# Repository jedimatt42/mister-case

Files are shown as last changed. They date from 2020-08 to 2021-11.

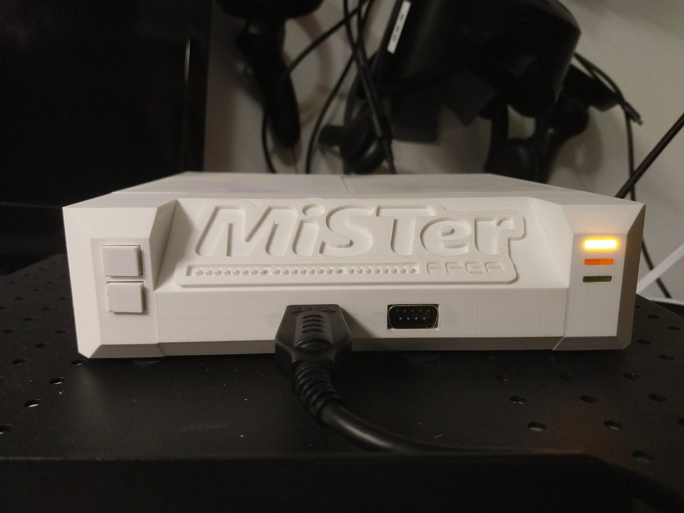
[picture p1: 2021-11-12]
images/front.jpg

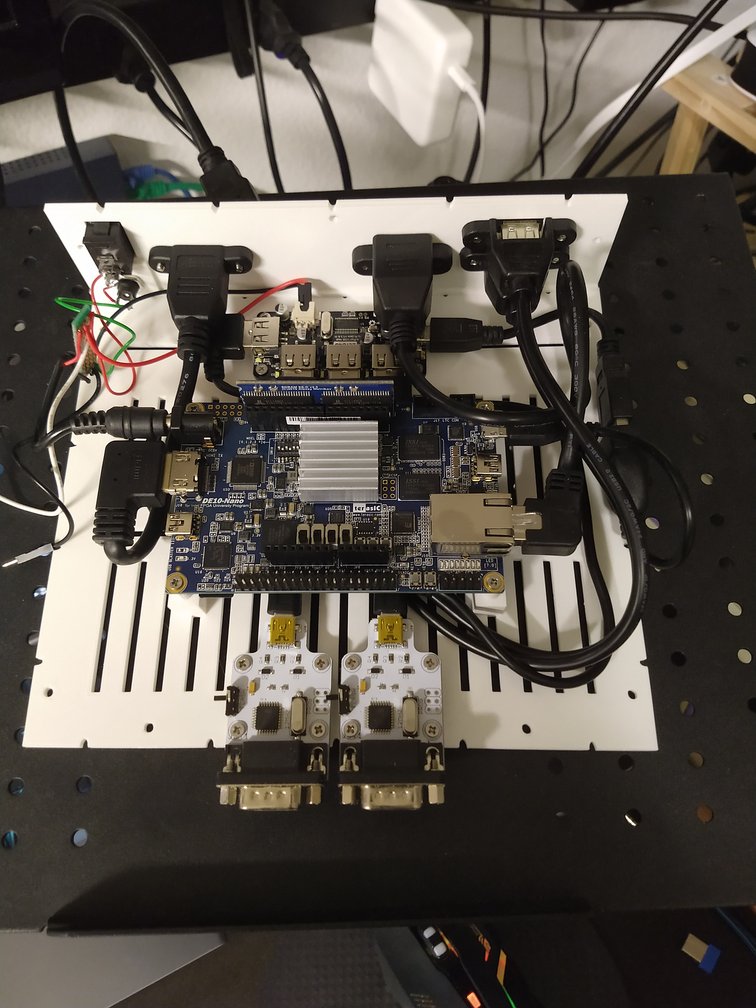
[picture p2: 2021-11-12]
images/guts.jpg

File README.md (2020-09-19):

# Custom MiSTer FPGA case

Designed to hold DE-10 Nano & slim 128MB SDRAM XS-D v2.5 boards

* Zero4U USB 2.0 powered USB hub
* With panel mount cables to bring ports to the back.
  * 2x powered USB
  * Ethernet
  * HDMI
  * 5v Power In
  * Power Switch
* 5v 30mm fan

Stylish front panel design with standard MiSTer switches and LEDs.

Note wiring of switches and LEDs from ioboard schematic:

https://github.com/MiSTer-devel/Hardware_MiSTer/blob/master/releases/iobrd_6.1.pdf

## LED

The GPIO pins appear to be active LOW, so the GND or cathode connects to the GPIO.
The anode is connected to 3.3v pin GPIO1[29] through individual 220-560 ohm resisters.

* `user` : GPIO1 pin 1  - RED
* `disk` : GPIO1 pin 3  - GREEN
* `power` : GPIO1 pin 5 - YELLOW

Connect a common lead from pin 29 to 3 resisters, each of which goes to an led, and then the negative terminal on the LED goes to the specific GPIO pin.

## Switches

switches are momentary, connecting the DE10 nano GPIO pin to GND (GPIO1[12]) when pressed.

* `reset` : GPIO1 pin 17
* `OSD`   : GPIO1 pin 13
* `user`  : GPIO1 pin 15

The left hand panel has room for 2 push button momentary switches, designed for the classic red button type: 

https://smile.amazon.com/DIYhz-Momentary-Pushbutton-Switches-Normally/dp/B08B1PWJ21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

For myself, I wire the top switch to OSD, and the bottom to USER which generally acts as in-core reset. For full MiSTer reset, the power switch on the back seems sufficient, or use the in menu option.

## LOGO for Mister

This projects uses an SVG MiSTer logo found on a forum... 

https://www.dropbox.com/s/gym92g5i8eauhdw/MISTER%20FPGA%20Logo.svg

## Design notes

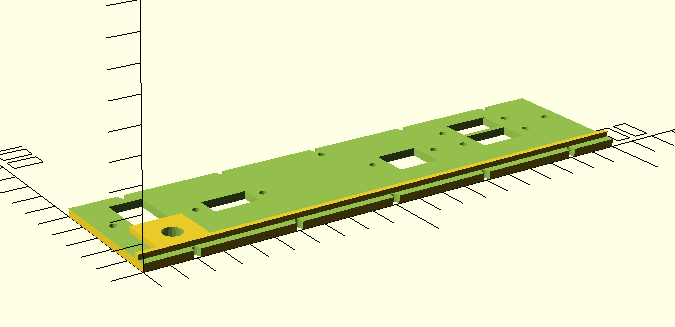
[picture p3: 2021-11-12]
images/back.png

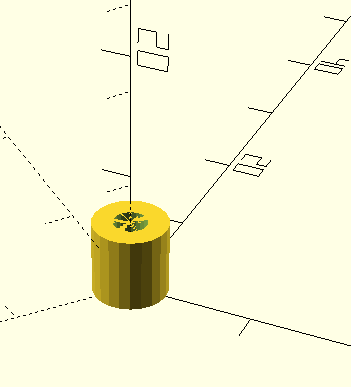
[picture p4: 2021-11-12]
images/spacer.png

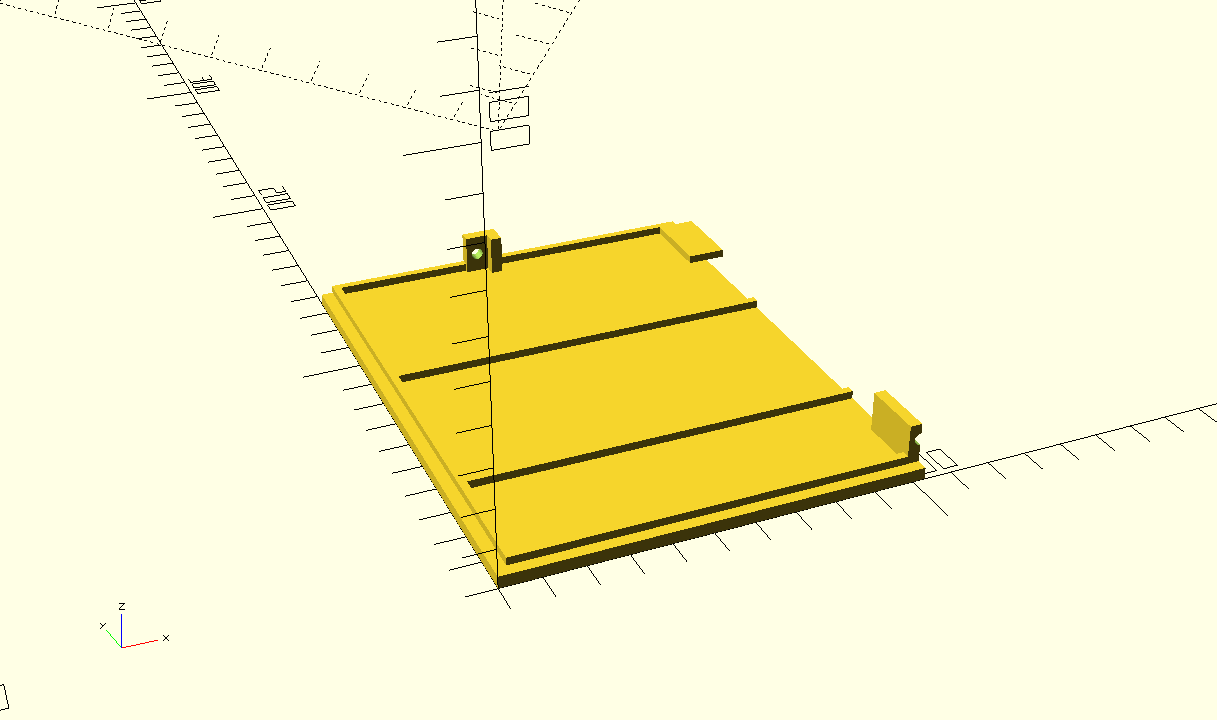
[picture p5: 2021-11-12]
images/top-left.png

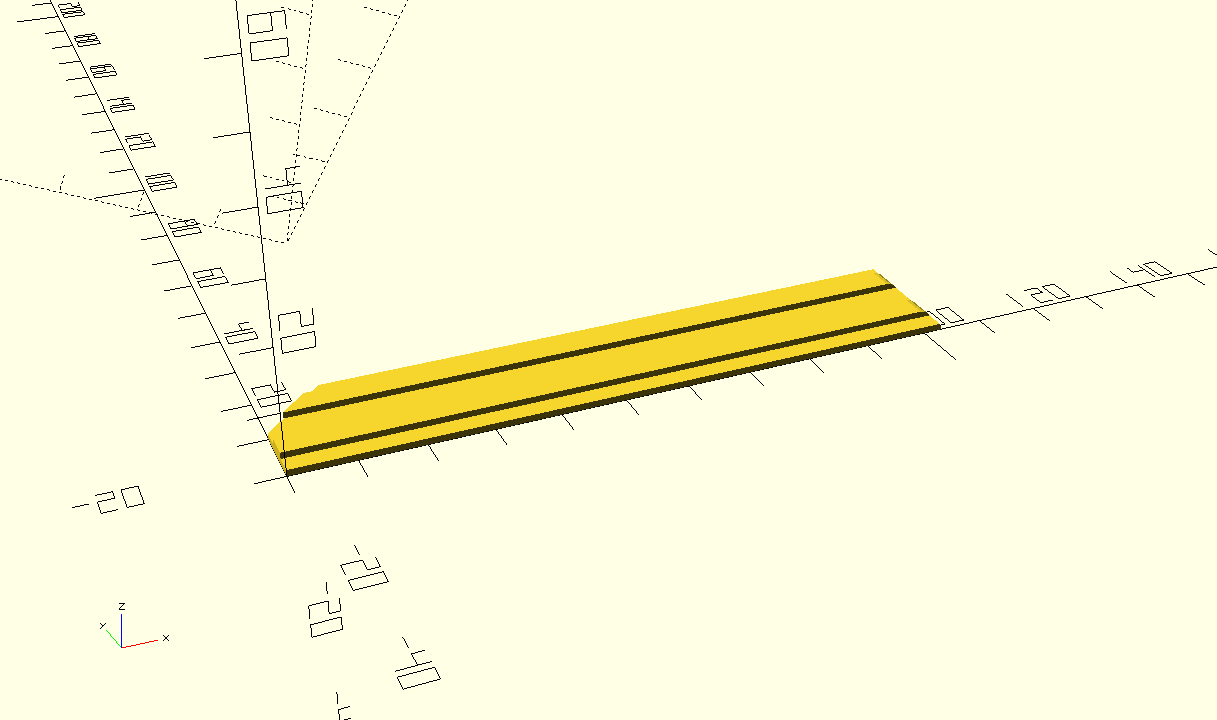
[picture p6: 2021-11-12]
images/right-seam.png

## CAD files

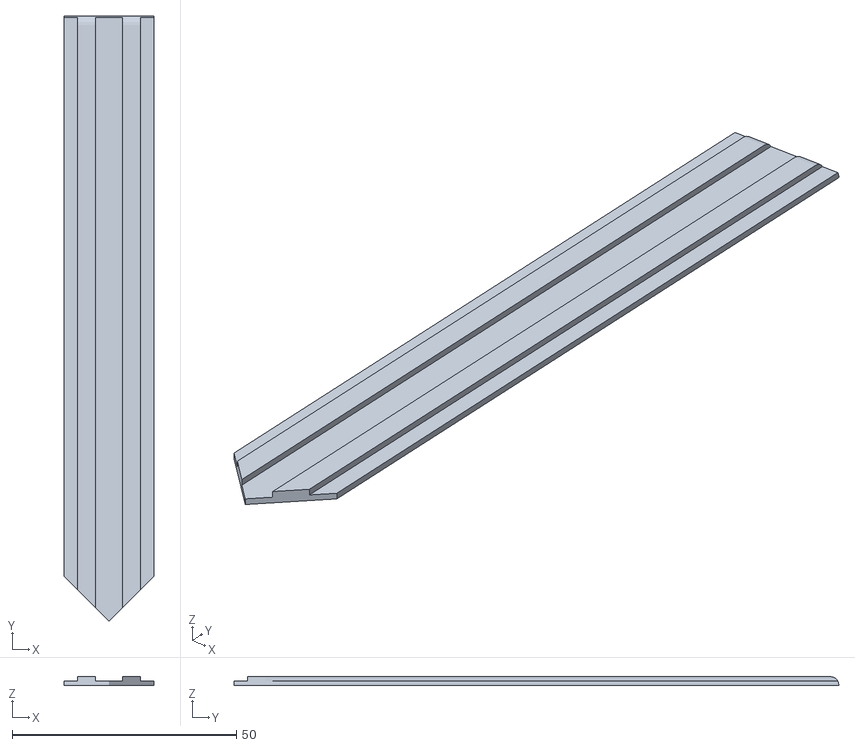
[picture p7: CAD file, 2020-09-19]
mister-console-seam-middle.stl
20.0 x 135.0 x 2.00

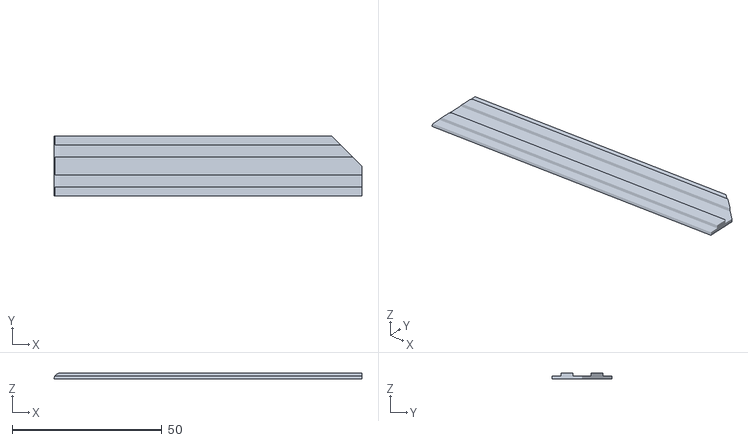
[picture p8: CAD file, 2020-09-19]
mister-console-seam-left.stl
103.0 x 20.0 x 2.00

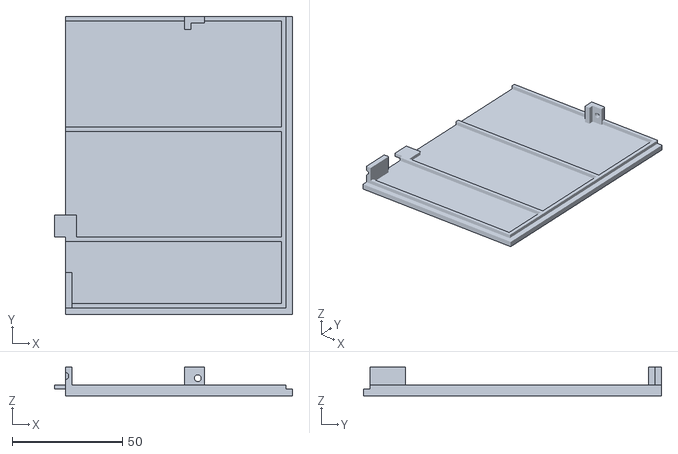
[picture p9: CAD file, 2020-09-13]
mister-console-cover-right.stl
108.0 x 135.0 x 13.0

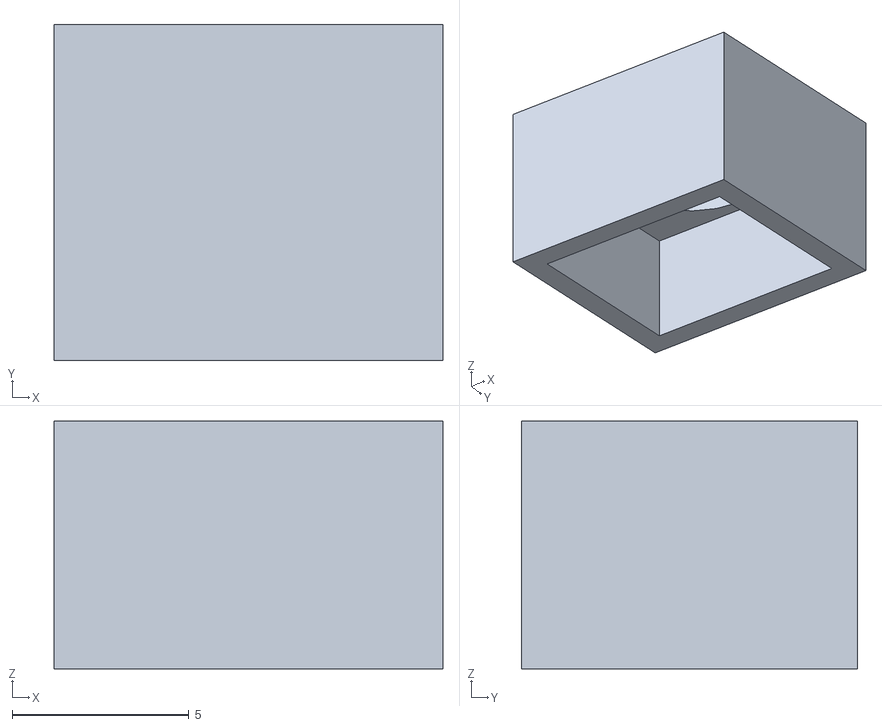
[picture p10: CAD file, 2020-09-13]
button.stl
11.0 x 9.50 x 7.00

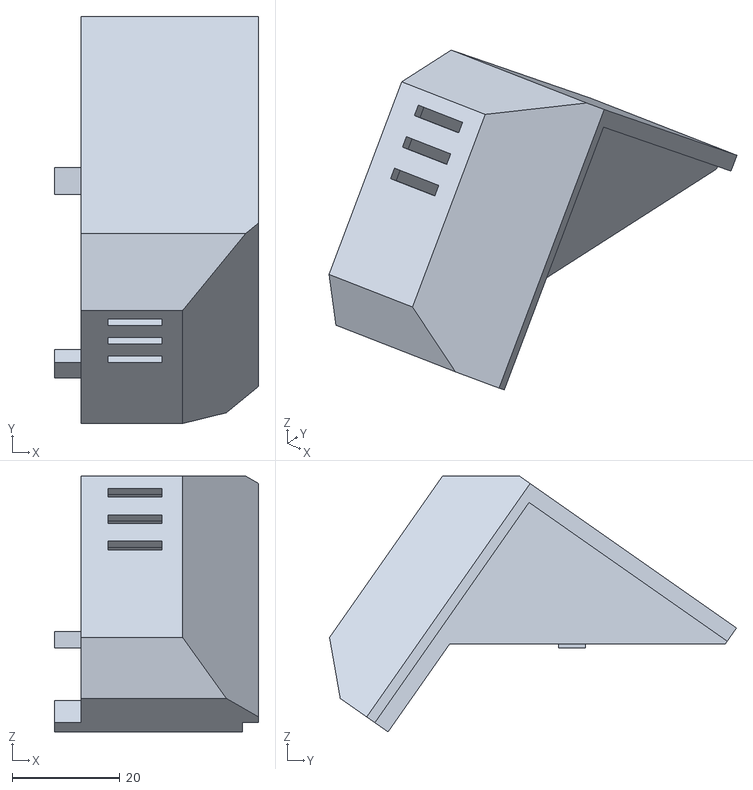
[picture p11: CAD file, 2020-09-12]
mister-console-front-right.stl
38.0 x 75.7 x 47.6

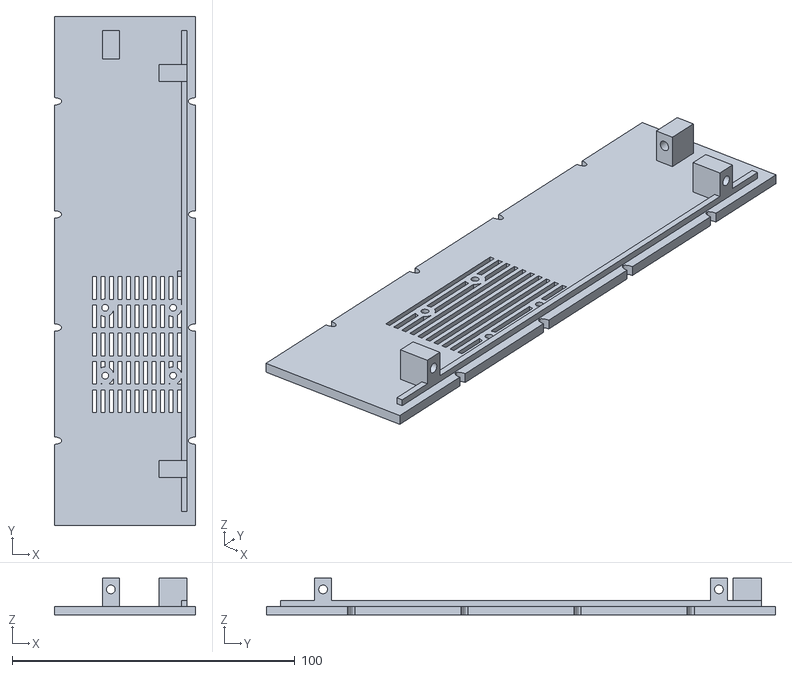
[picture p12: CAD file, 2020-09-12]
mister-console-left.stl
50.0 x 180.0 x 13.0

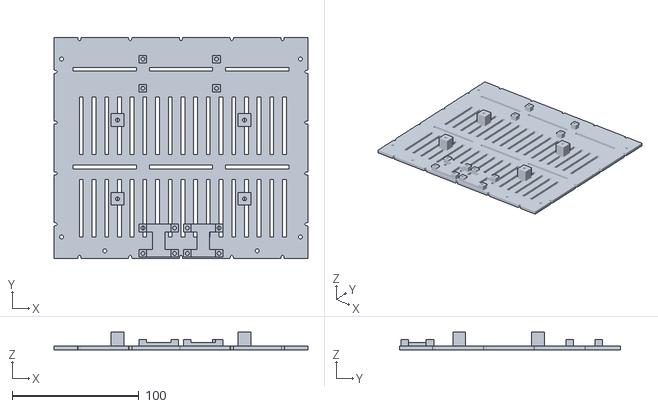
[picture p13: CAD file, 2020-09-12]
mister-console-bottom.stl
200.0 x 174.0 x 14.0

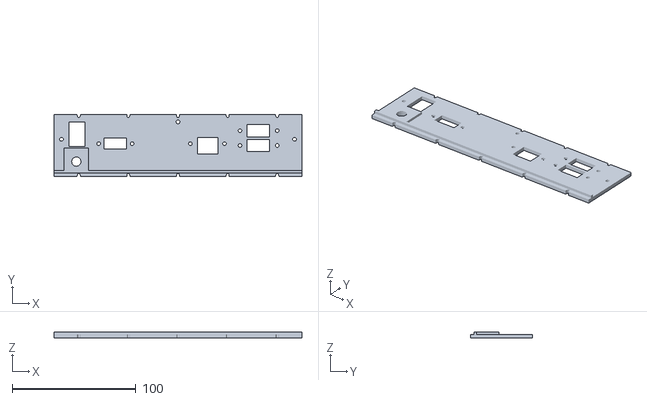
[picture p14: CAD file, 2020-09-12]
mister-console-back.stl
200.0 x 50.0 x 5.00

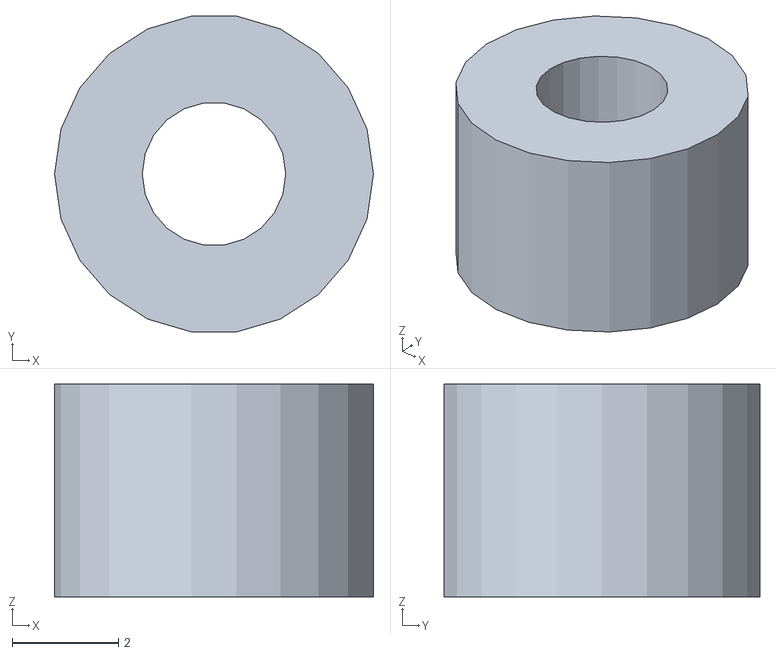
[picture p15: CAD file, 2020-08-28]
spacer.stl
6.00 x 5.94 x 4.00

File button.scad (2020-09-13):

module button_cap() {
    x=11;
    z=9.5;
    
    difference() {
        cube([x,7,z]);
        
        translate([1,2.5,1])
        cube([x-2,5.5,z-2]);
        
        translate([x/2,1.5,z/2])
        rotate([-90,0,0])
        cylinder(h=2,r=3.25,$fn=20);
    }
}

rotate([-90,0,0])
translate([0,-7,0])
button_cap();

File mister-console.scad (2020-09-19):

// outer box dimensions
sh_x=200;
sh_y=180;
sh_z=50;

// power switch dimensions
psw_x=13;
psw_y=20;
psw_z=20;

// standoff details
mister_depth=62;
mister_width=100;

hub_width=23;
hub_depth=58;

// brass threaded inset
thread_inset=1.55;

// rotational segment count
$fn=24;

module switch() {
    cube([psw_x,psw_y,psw_z]);
}

module powerjack() {
    thread_radius=3.75;
    lip_radius=5.25;
    
    rotate([-90,0,0])
    union() {
        cylinder(h=10,r=thread_radius,center=false);
        translate([0,0,10])
        cylinder(h=5,r=lip_radius,center=false);
    }
}

module etherjack() {
    ejx=16.5;
    ejz=13.5;
    ejy=20;
    // hole spacing
    ejhs=27.5;
    
    translate([5.75,0,0])
    cube([ejx,ejy,ejz]);
    
    translate([ejhs,0,8.5])
    rotate([-90,0,0])
    union() {
        cylinder(h=ejy,r=1.5,center=false);
        translate([0,0,ejy-1.5])
        cylinder(h=1.5,r=3,center=false);
    }

    translate([0,0,8.5])
    rotate([-90,0,0])
    union() {
        cylinder(h=ejy,r=1.5,center=false);
        translate([0,0,ejy-1.5])
        cylinder(h=1.5,r=3,center=false);
    }
}

module hdmi_jack() {
    hdx=18;
    hdz=9;
    hdy=20;
    // hole spacing
    hdhs=27;
    
    translate([(hdhs-hdx)/2,0,0])
    cube([hdx,hdy,hdz]);
    
    translate([hdhs,0,hdz/2])
    rotate([-90,0,0])
    union() {
        cylinder(h=hdy,r=1.5,center=false);
        translate([0,0,hdy-1.5])
        cylinder(h=1.5,r=3,center=false);
    }

    translate([0,0,hdz/2])
    rotate([-90,0,0])
    union() {
        cylinder(h=hdy,r=1.5,center=false);
        translate([0,0,hdy-1.5])
        cylinder(h=1.5,r=3,center=false);
    }
}

module usb_jack() {
    hdx=18;
    hdz=10;
    hdy=20;
    // hole spacing
    hdhs=30;
    
    translate([5.75,0,0])
    cube([hdx,hdy,hdz]);
    
    translate([hdhs,0,hdz/2])
    rotate([-90,0,0])
    union() {
        cylinder(h=hdy,r=1.5,center=false);
        translate([0,0,hdy-1.5])
        cylinder(h=1.5,r=3,center=false);
    }

    translate([0,0,hdz/2])
    rotate([-90,0,0])
    union() {
        cylinder(h=hdy,r=1.5,center=false);
        translate([0,0,hdy-1.5])
        cylinder(h=1.5,r=3,center=false);
    }
}

module fan_screw() {
    cylinder(h=10,r=1.2,center=false);
    
    translate([0,0,5])
    cylinder(h=3,r=2.1,center=false);
}

module fan() {
    cube([8,30,30]);

    translate([3,30-3,30-3])
    rotate([0,-90,0])
    fan_screw();
    
    translate([3,30-3,3])
    rotate([0,-90,0])
    fan_screw();
    
    translate([3,3,30-3])
    rotate([0,-90,0])
    fan_screw();
    
    translate([3,3,3])
    rotate([0,-90,0])
    fan_screw();
}

module side_vent() {
    // horizontal slats - partial depth
    for(x=[0:3:30])
    translate([1,0,x])
    cube([2,50,1.5]);
    
    // vertical cut in from outside
    for(x=[0:10:40])
    translate([0,x,0])
    cube([1,8,33]);
}
    
module fan_mount() {
    difference() {
        side_vent();
        
        // leave behind mounting support
        translate([3,13,3])
        rotate([0,-90,0])
        cylinder(h=2,r=3.1,center=false);

        translate([3,13+24,3])
        rotate([0,-90,0])
        cylinder(h=2,r=3.1,center=false);
        
        translate([3,13,3+24])
        rotate([0,-90,0])
        cylinder(h=2,r=3.1,center=false);
        
        translate([3,13+24,3+24])
        rotate([0,-90,0])
        cylinder(h=2,r=3.1,center=false);
    }
}

module screw_hole() {
    cylinder(h=20,r=thread_inset,center=false);
}

module nine_pin() {
    union() {
        cube([31,40.5,15]);
    
        // todo: shape this more precisely, rounded/tapered...
        translate([(31-18)/2,-6,(15-9.3)/2])
        cube([18,6,9.3]);
        
        translate([-1.5,0,-3])
        cube([34,14.5,6]);

        translate([-1.5,3,-5])
        cube([34,11.5,6]);
        
        translate([2.9,-5,7.5])
        rotate([-90,0,0])
        cylinder(h=5,r=2.8,center=false);

        translate([31-2.9,-5,7.5])
        rotate([-90,0,0])
        cylinder(h=5,r=2.8,center=false);
    }
}

module push_button() {
    rotate([-90,0,0])
    cylinder(h=22,r=4,center=false);
    
    translate([-7,12.5,-8])
    cube([14,60,16]);
    
    translate([-6,0,-5.25])
    cube([12,10.5,10.5]);
}

module junk_in_the_box() {
    translate([12,sh_y-18,sh_z-psw_z-6])
    switch();
    
    translate([18,sh_y-14,12])
    powerjack();
    
    translate([36,sh_y-20,22])
    hdmi_jack();
    
    translate([sh_x-50,sh_y-20,8+24])
    usb_jack();
    
    translate([sh_x-50,sh_y-20,8+12])
    usb_jack();
    
    //translate([sh_x-50,sh_y-20,8])
    //usb_jack();
    
    translate([sh_x-90,sh_y-20,18])
    etherjack();
    
    translate([0,50,5])
    fan();
    
    translate([-3,40,5])
    fan_mount();
    
    translate([sh_x+3,40,5])
    scale([-1,1,1])
    side_vent();
    
    // 9pin ports
    translate([70-3,-10.3,8])
    nine_pin();
    
    translate([sh_x-70-25-3,-10.3,8])
    nine_pin();
    
    // bottom assembly screw holes
    translate([6,20,-5])
    screw_hole();
    translate([6,sh_y-20,-5])
    screw_hole();
    translate([sh_x-6,20,-5])
    screw_hole();
    translate([sh_x-6,sh_y-20,-5])
    screw_hole();
    
    // rear assembly screw holes
    translate([6,sh_y-15,sh_z-20])
    rotate([-90,0,0])
    screw_hole();    
    translate([sh_x-6,sh_y-15,sh_z-20])
    rotate([-90,0,0])
    screw_hole();
    translate([100,sh_y-15,sh_z-6])
    rotate([-90,0,0])
    screw_hole();
    
    // front to bottom screw holes
    translate([40,9,-5])
    screw_hole();
    translate([sh_x-40,9,-5])
    screw_hole();
    
    // front to top screw holes
    translate([40,35,sh_z-5])
    rotate([-90,0,0])
    screw_hole();

    translate([sh_x-40,35,sh_z-5])
    rotate([-90,0,0])
    screw_hole();
    
    // leds
    translate([sh_x-25,-20,sh_z-10])
    cube([10,40,2]);

    translate([sh_x-25,-20,sh_z-16])
    cube([10,40,2]);
    
    translate([sh_x-25,-20,sh_z-22])
    cube([10,40,2]);
    
    // led block cutout
    translate([sh_x-27,-14,sh_z-37])
    cube([14,60,30]);
    
    // push buttons
    translate([21,-16,37])
    push_button();
    
    translate([21,-16,25])
    push_button();
}

module mister_standoff() {
    difference() {
        translate([-5,-5,0])
        cube([10,10,14]);
        
        translate([0,0,2])
        cylinder(h=12,r=thread_inset,center=false);
    }
}

module mister_standoffs() {
    mister_standoff();

    translate([mister_width,0,0])
    mister_standoff();
    
    translate([0,mister_depth,0])
    mister_standoff();
    
    translate([mister_width,mister_depth,0])
    mister_standoff();
}

module hub_standoff() {
    difference() {
        translate([-3,-3,0])
        cube([6,6,8]);
        
        translate([0,0,2])
        cylinder(h=6,r=thread_inset,center=false);        
    }
}

module gen_standoffs(width, depth) {
    hub_standoff();

    translate([width,0,0])
    hub_standoff();
    
    translate([0,depth,0])
    hub_standoff();
    
    translate([width,depth,0])
    hub_standoff();
}

module hub_standoffs() {
    gen_standoffs(hub_width, hub_depth);
}

module mjdc_standoffs() {
    gen_standoffs(25, 20);
    
    translate([7.5,0,0])
    cube([10,20,6]);
    
    translate([1.5,-3,0])
    cube([22,6,6]);
    
    translate([1.5,17,0])
    cube([22,6,6]);
}


module bottom_vent(x) {
    translate([x,20,0])
    cube([3,45,3]);

    translate([x,85,0])
    cube([3,45,3]);
}

module stress_cutouts(limit) {
    for(x=[20:40:limit])
    translate([x,0,0])
    scale([1,2,1])
    cylinder(h=10,r=1.3,center=false);  
}

module shell_bottom() {
    th=3;
    thx2=th*2;
    
    difference() {
        union() {
            difference() {
                translate([0,th,0])
                cube([sh_x,sh_y-thx2,sh_z]);
                
                translate([0,0,th])
                cube([sh_x,sh_y,sh_z]);

                for(x=[20:10:sh_x-20])
                bottom_vent(x);
            }
            
            translate([50,50,0])
            mister_standoffs();
            
            translate([70,160,0])
            rotate([0,0,-90])
            hub_standoffs();
            
            translate([70,7,0])
            mjdc_standoffs();
            
            translate([sh_x-70-25,7,0])
            mjdc_standoffs();
        }
    
        junk_in_the_box();
        
        // stress relief
        translate([0,3,-4])
        stress_cutouts(sh_x-10);
    
        translate([0,sh_y-3,-4])
        stress_cutouts(sh_x-10);
        
        translate([0,10,-4])
        rotate([0,0,90])
        stress_cutouts(sh_y-10);
        
        translate([200,10,-4])
        rotate([0,0,90])
        stress_cutouts(sh_y-10);
        
        for(x=[15:60:sh_x-18])
        translate([x,73.5,0])
        cube([50,3,3]); 
        
        for(x=[15:60:sh_x-18])
        translate([x,150.5,0])
        cube([50,3,3]); 
    }
}


module bracket() {
    translate([0,-3,0])
    cube([10,6,10]);
}
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

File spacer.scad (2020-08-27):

difference() {
    cylinder(h=6,r=3,$fn=22);
    
    cylinder(h=6,r=1.35,$fn=22);
}

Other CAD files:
mister-console-seam-right.stl
mister-console-cover-left.stl
mister-console-front-left.stl
mister-console-right.stl

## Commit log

2020-08-13 first pass at back panel cutouts
    [mister-console.scad]
2020-08-15 break apart back panel from bottom
    add venting on bottom.
    add butt joint
    [mister-console.scad]
2020-08-15 right and left side panels
    [mister-console.scad]
2020-08-15 more space on rear left and right edge
    [mister-console.scad]
2020-08-16 Zero4U usb hub standoffs
    [mister-console.scad]
2020-08-16 Document how LED and switches are connected to GPIO
2020-08-27 4 panels complete.
    rear, left, right, and bottom.
    [mister-console.scad]
2020-08-27 scalable screw spacer if you need more lift.
    [spacer.scad]
2020-08-28 front face with mister logo
    [mister-console.scad, spacer.stl]
2020-08-30 break the face into 3 parts
    [mister-console.scad]
2020-09-13 maybe top covers
    [button.scad, button.stl, mister-console-cover-left.stl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]
2020-09-19 stylish flair to cover the plastic plate seam
    [mister-console-seam-left.stl, mister-console-seam-middle.stl, mister-console-seam-right.stl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]
